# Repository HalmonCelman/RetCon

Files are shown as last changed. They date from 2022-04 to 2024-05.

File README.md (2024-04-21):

# RetCon

Mini Retro Console

Based on LLL language, works on FatFS.
Display: WG12864B1 V1.0-SFYLYHTC06
CPU: Atmega1284p

to run properly LLL( with FatFS ) you need to have at least 3K internal SRAM memory

## Dependencies
- avr-gcc
- avrdude
- cmake

## Build and Run

in program/
```
./configure.sh
./build.sh
./upload.sh
```

*if you are not using usbasp you should change upload.sh*

## Schematic

you can find schematic in `schematic_and_others/schematic` and modify it in KiCAD, or just look below:

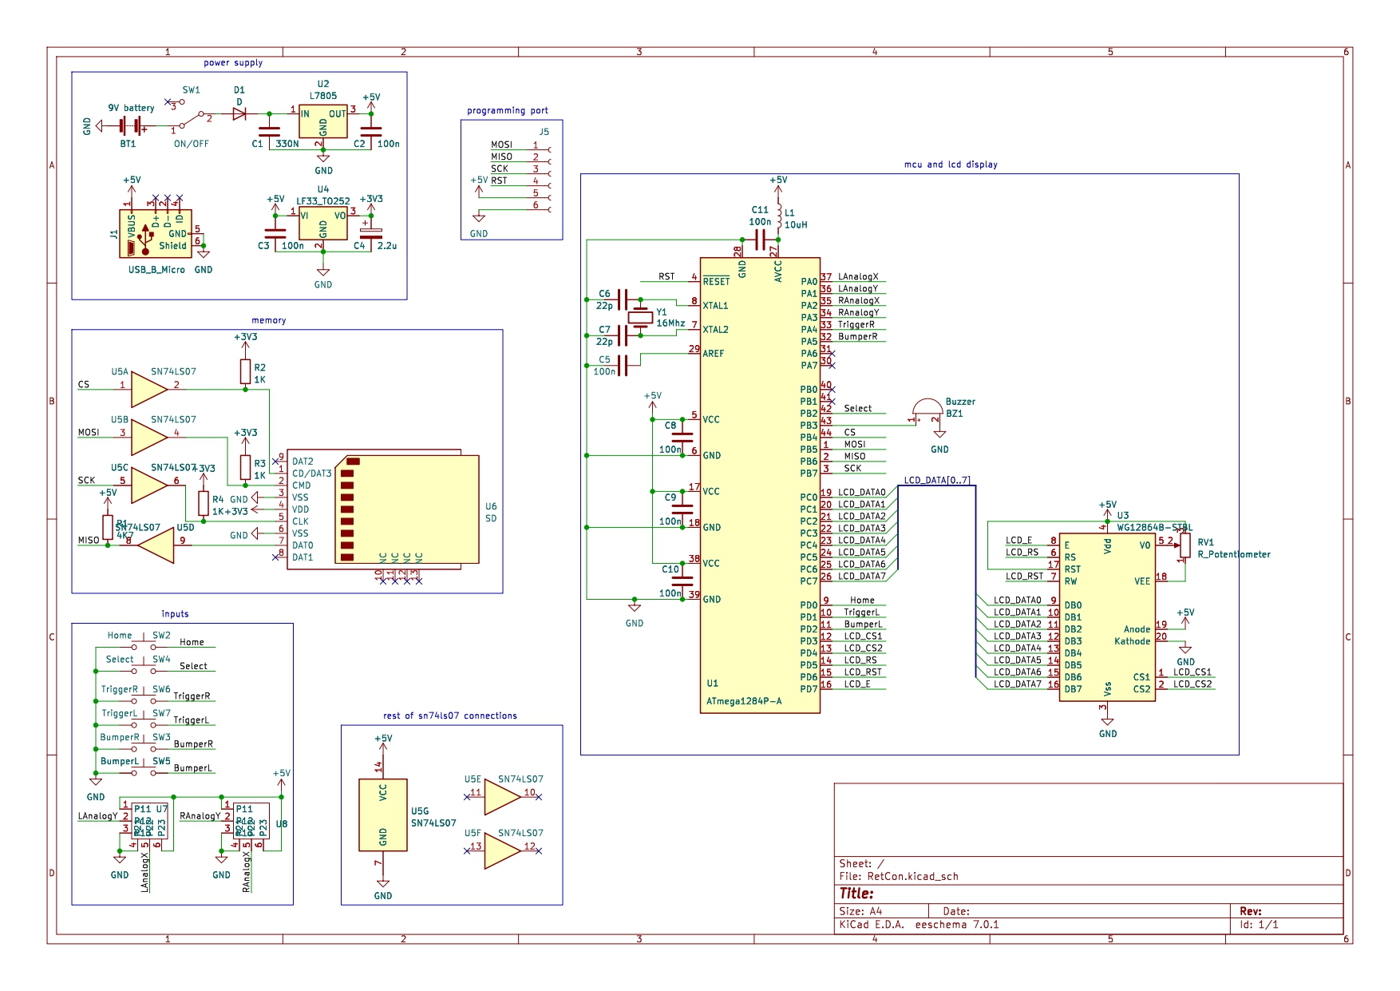
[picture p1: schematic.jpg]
Schematic schematic of RetCon


## Board and Reality

here are some pictures how the board has been designed and how it looks in reality

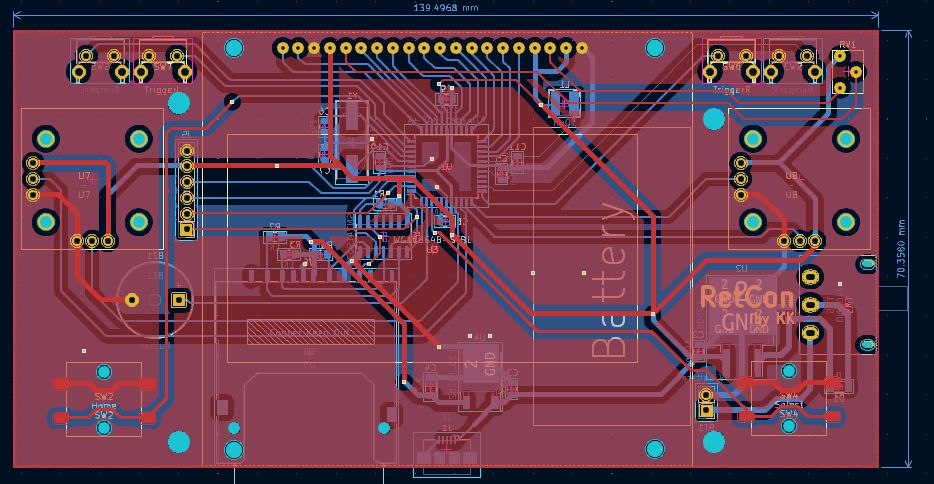
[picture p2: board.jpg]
Board board design


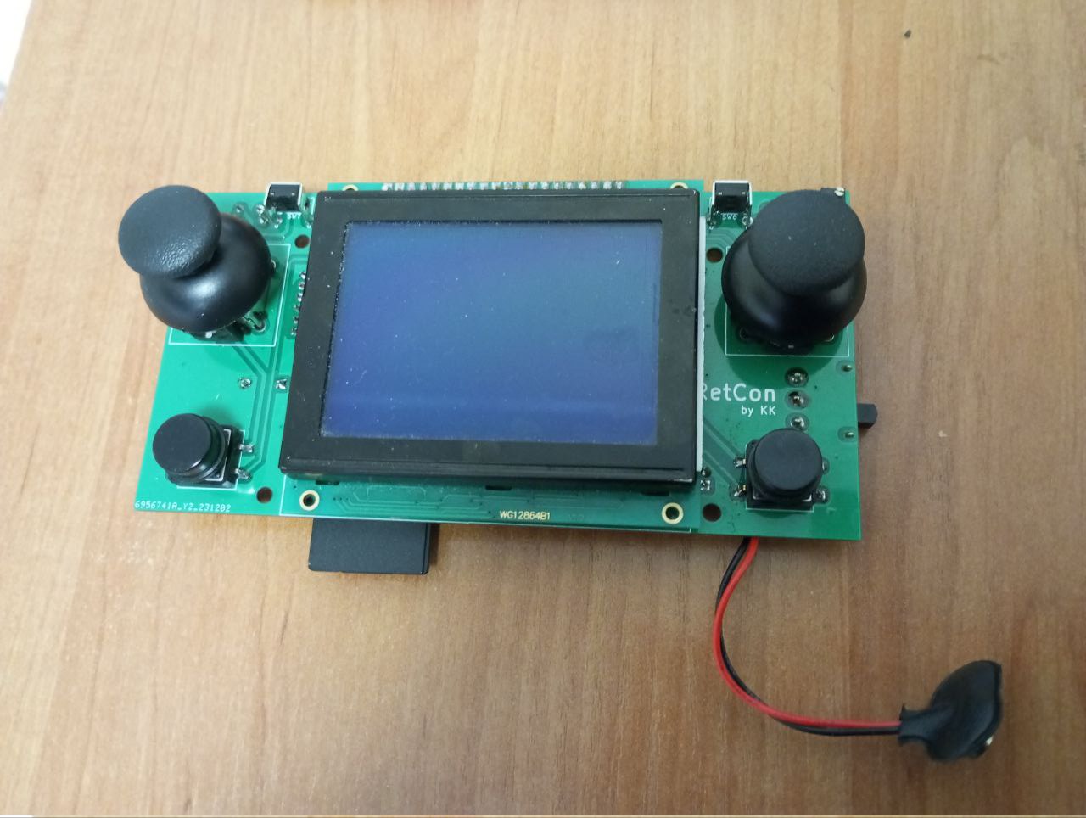
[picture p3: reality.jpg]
Reality reality


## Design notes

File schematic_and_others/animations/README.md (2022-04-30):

How to create animation for this system?

You have two options

A. to do automatically:

1. Create animation in gimp or another program.
2. Export to *gif
3. Convert to *.wbmp with https://convertio.co/pl/gif-wbmp/ or any similiar converter
4. Download zip
5. Unpack to animacje/frames/
6. run from terminal ./manima.sh
7. write how your gif was named ->f.e your gif - a.gif then you write a
8. copy prefix (if you have files in frame/a f.e. abc0.wbmp abc1.wbmp then you should copy abc) and paste it
9. give how you would name your animation
10. done! your animation is in folder exported/

OR

B. manually
1. Create animation in gimp or another program.
2. Export to *gif
3. Convert to *.wbmp with https://convertio.co/pl/gif-wbmp/ or any similiar converter
4. Download zip
5. Unpack to animacje/frames/
6. run from terminal ./rrator.sh
7. write how your gif was named ->f.e your gif - a.gif then you write a
8. copy prefix (if you have files in frame/a f.e. abc0.wbmp abc1.wbmp then you should copy abc) and paste it
9. give how you would name your animation
10. run ./condator.sh
11. write this same as in 7 point
12. write this same as in 9 point
13. run ./exportator.sh
14. write this same as in point 9 and 12
15. done! your animation is in folder exported/

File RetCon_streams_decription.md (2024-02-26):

# RetCon Streams Description

> This file decribes IN and OUT recieved from LLL, and it's functions

**! *0 values mean that parameter isn't processed but still 1 parameter is necessary in program, I recommend to write in his place @0* !**

**! *more than 1 value should be given by range, or by separating out command into multiple out commands with same stream* !**

## for OUT:
> ### 0. Error 
> 
> > Display error information
> > 
> > 1 value
> > - error number
>
> ### 1. Refreshes the screen
> 
> > 0 values
>
> ### 2. Clear screen buffer
> > Clears all the screen buffer
> > (if double buffering isn't used - clears screen)
> >
> > 0 values
> 
> ### 3. SetPixel
> > Sets pixel in screen buffer
> > 
> > 2 values
> > - X axis [0:127]
> > - Y axis [0:63]
>
> ### 4. ClearPixel
> > Clears pixel in screen buffer
> > 
> >  2 values
> > - X axis [0:127]
> > - Y axis [0:63]
>
> ### 5. WriteChar
> > Write Char on screen, x and y indicates position of top left pixel of letter, letters size are 5x7 
> > 
> >  3 values
> > - X axis [0:121]
> > - Y axis [0:63]
> > - char
> 
> ### 6. Stroke Rect
> > Draws a rectangle which isn't filled inside
> > 
> >  4 values
> >  - X start axis [0:127]
> >  - Y start axis [0:63]
> >  - X length
> >  - Y length
> 
> ### 7. Fill Rect
> > Draws a rectangle which is filled inside
> > 
> >  4 values
> >  - X start axis [0:127]
> >  - Y start axis [0:63]
> >  - X length
> >  - Y length
> 
> ### 8. Beep
> > Beep with buzzer for up to 255 ms (this don't stop program from execuitng)
> >
> > *believe me you don't want to turn this buzzer for longer time,
> >  but chill, in the RetCon v1.1 you should be able to play some music with it*
> >
> > 1 value
> > - time of beeping
> ### 9. Delay - in miliseconds
> > Stop executing anything for up to 65535 ms
> >
> > 2 values
> > - 16 bits value
> >
> ### 10. setTimer
> > sets timer which decerase every milisecond and stops at 0
> >
> >  2 values
> >  - 16 bits value

## for IN:

> ### 0. Error Stream
> > Check if any error exist, if yes get his number
> > 
> > 1 value
> > - error number
> >
> ### 1. get 1-0 buttons value
> > if button is pressed, at its position 1 is set, for positions see buttons.pdf
> >
> > 1 value
> > - bits for all buttons
> >
> ### 2. get analog 1 value
> > 
> > gets value from left analog
> > 
> > - 1 value
> >
> ### 3. get analog 2 value
> > 
> > gets value from right analog
> > 
> > - 1 value
>
> ### 10. getTimer
> > gets timer value
> >
> >  2 values
> >  - 16 bits value

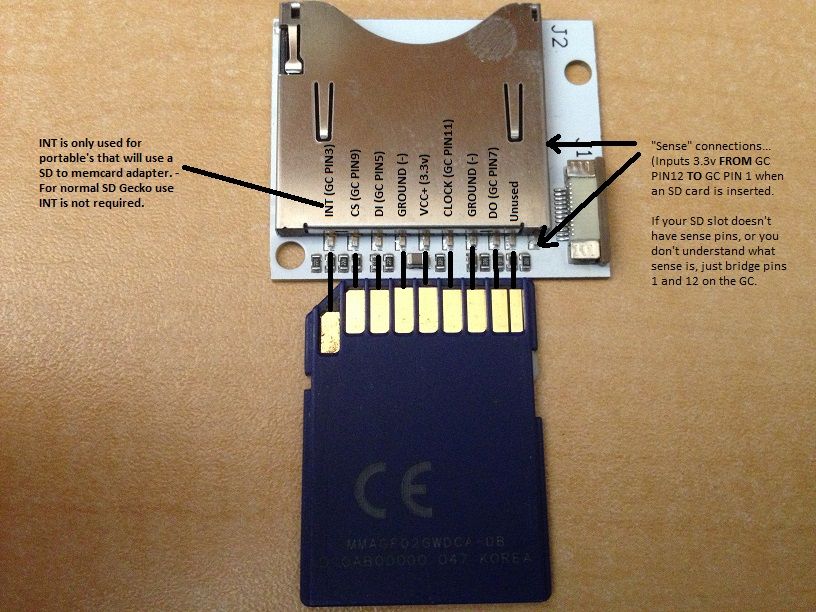
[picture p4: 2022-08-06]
schematic_and_others/documentations/SD_pinout.jpg

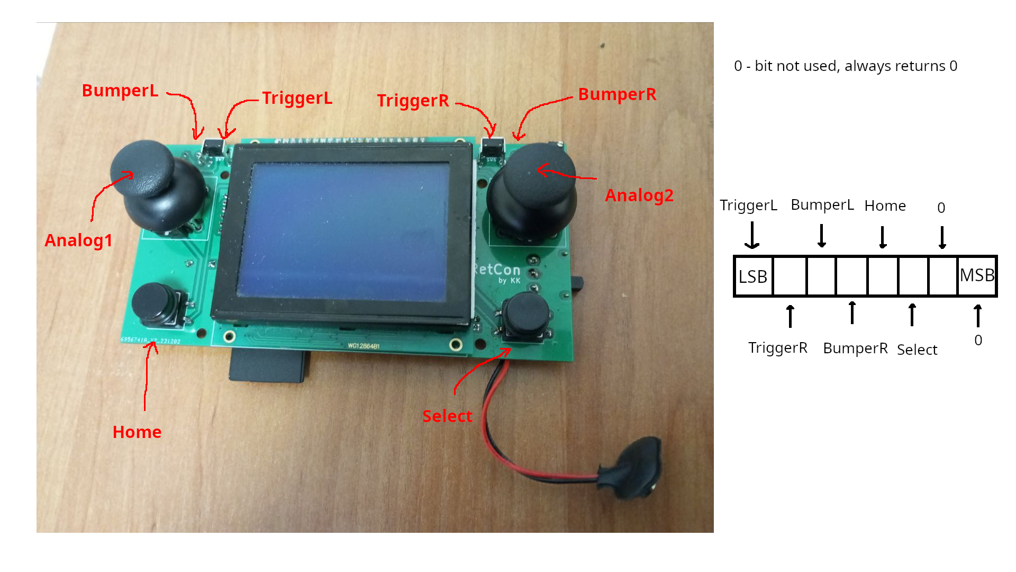
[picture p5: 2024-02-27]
buttons.png

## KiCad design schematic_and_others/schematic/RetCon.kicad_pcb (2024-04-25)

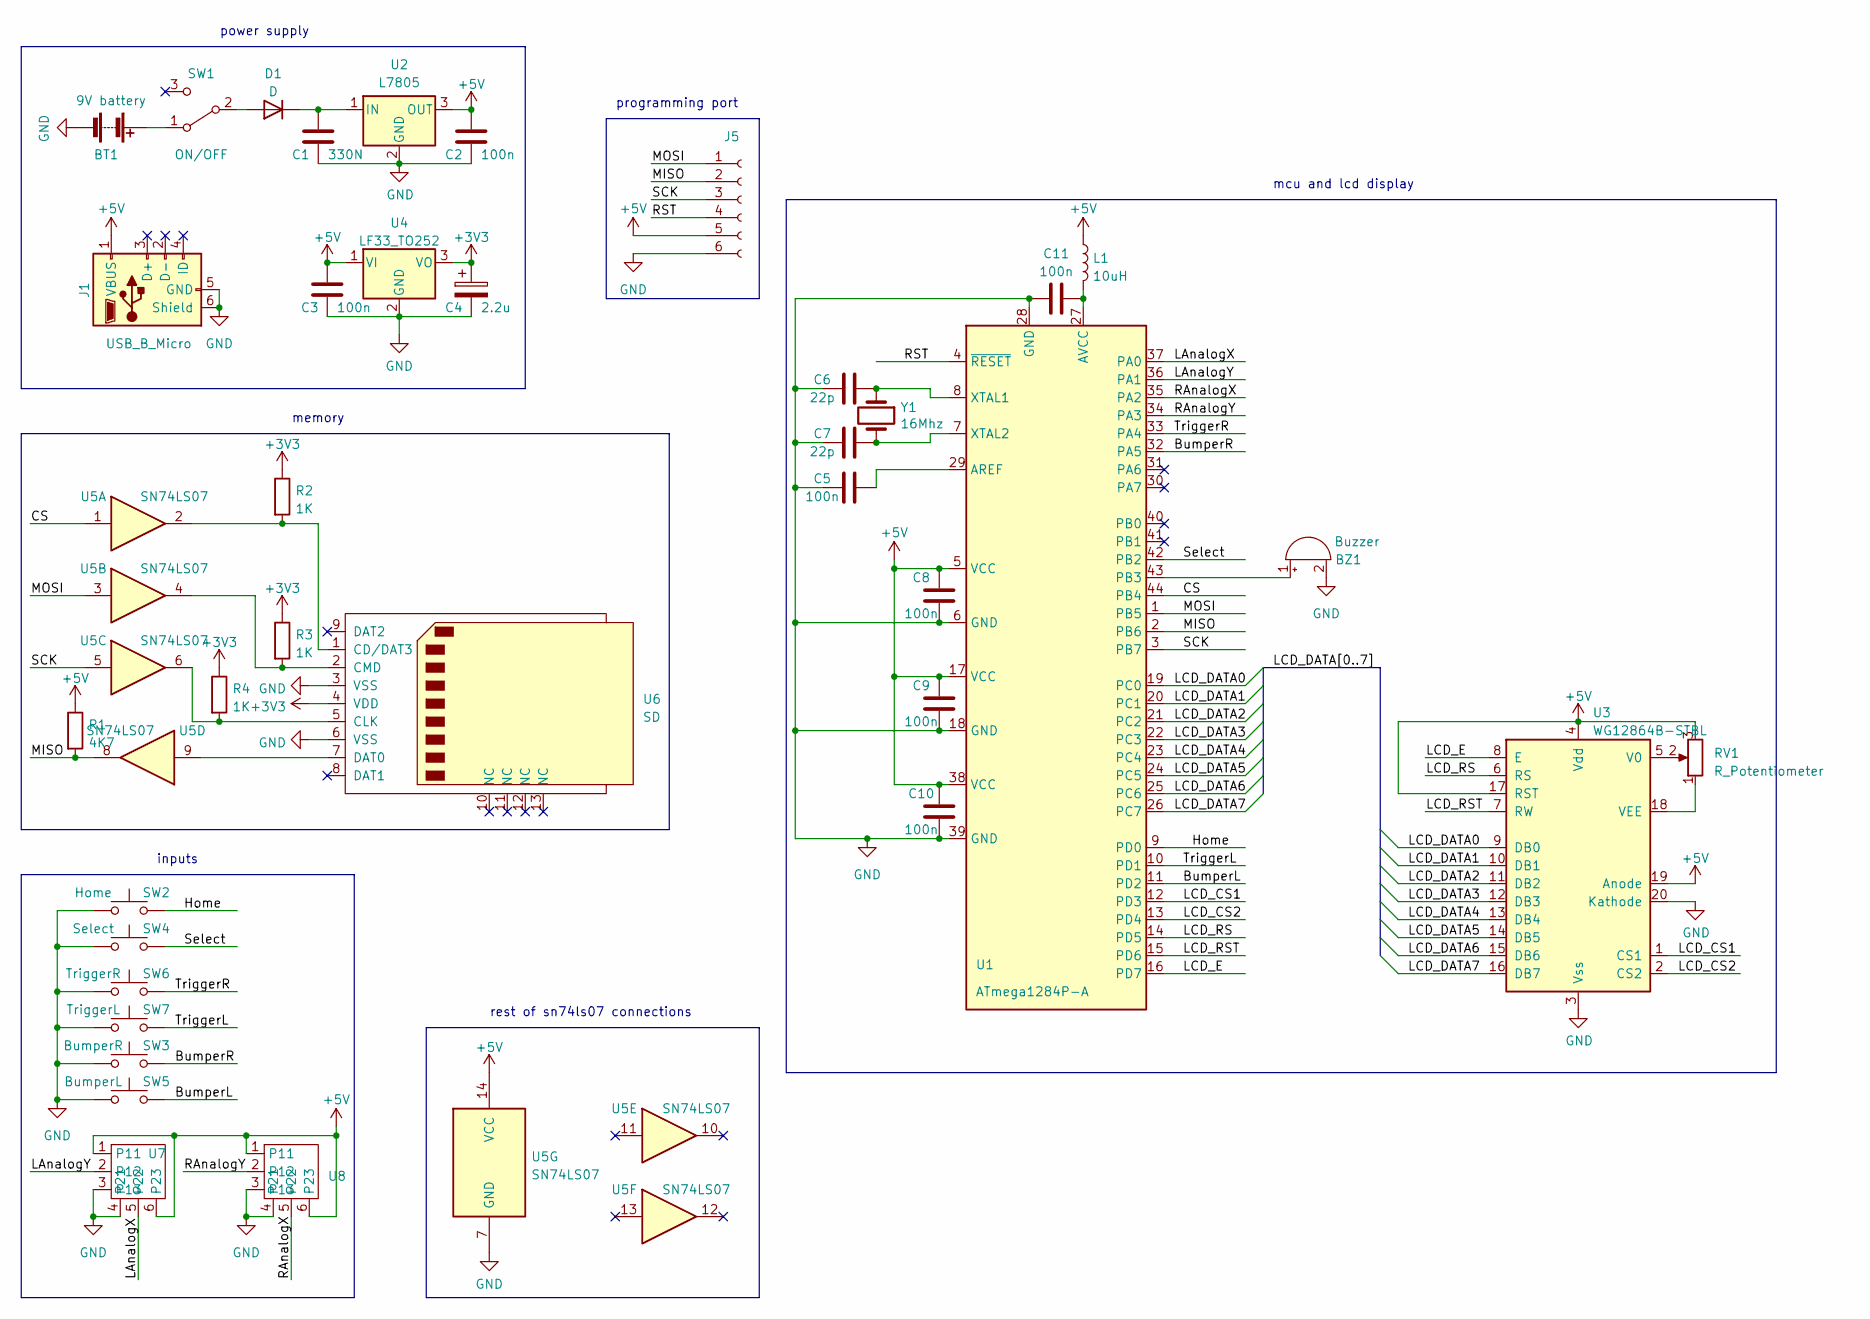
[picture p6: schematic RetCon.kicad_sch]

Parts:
BT1: 9V battery; PinSocket_1x02_P2.54mm_Vertical
BZ1: Buzzer; Buzzer_12x9.5RM7.6
C1: 330N; C_0805_2012Metric
C2, C3, C5, C8, C9, C10, C11: 100n; C_0805_2012Metric
C4: 2.2u; C_1206_3216Metric
C6, C7: 22p; C_0805_2012Metric
D1: D; C_1206_3216Metric
J1: USB_B_Micro; USBMicro-SMD
J5: PinSocket_1x06_P2.54mm_Vertical
L1: 10uH; L_Bourns-SRN4018
R1: 4K7; R_0805_2012Metric_Pad1.20x1.40mm_HandSolder
R2, R3, R4: 1K; R_0805_2012Metric_Pad1.20x1.40mm_HandSolder
RV1: R_Potentiometer; potentiometer10K
SW1: ON/OFF; Button_Switch
SW2: Home; buttonSMD_withHoles
SW3: BumperR; SW_Tactile_SPST_Angled_PTS645Vx31-2LFS
SW4: Select; buttonSMD_withHoles
SW5: BumperL; SW_Tactile_SPST_Angled_PTS645Vx31-2LFS
SW6: TriggerR; SW_Tactile_SPST_Angled_PTS645Vx31-2LFS
SW7: TriggerL; SW_Tactile_SPST_Angled_PTS645Vx31-2LFS
U1: ATmega1284P-A; TQFP-44_10x10mm_P0.8mm
U2: L7805; TO-263-2
U3: WG12864B-STBL; WG12864BL
U4: LF33_TO252; TO-252-2
U5: SN74LS07; SO-14_3.9x8.65mm_P1.27mm
U6: SD; SD_Kyocera_145638009511859+
U7, U8: joystickTHT
Y1: 16Mhz; Crystal_SMD_HC49-SD

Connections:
+3V3: C4.1, R2.1, R3.1, R4.1, U4.3 (VO), U6.4 (VDD)
+5V: C2.1, C3.1, C8.2, C9.2, C10.2, J1.1 (VBUS), J5.5, L1.1, R1.1, RV1.3, U1.5 (VCC), U1.17 (VCC), U1.38 (VCC), U2.3 (OUT), U3.4 (Vdd), U3.17 (RST), U3.19 (Anode), U4.1 (VI), U5.14 (VCC), U7.1 (P11), U7.6 (P23), U8.1 (P11), U8.6 (P23); also elsewhere on the board
/BumperL: SW5.2, U1.11 (PD2)
/BumperR: SW3.1, U1.32 (PA5)
/CS: U1.44 (PB4), U5.1
/Home: SW2.2, U1.9 (PD0)
/LAnalogX: U1.37 (PA0), U7.5 (P22)
/LAnalogY: U1.36 (PA1), U7.2 (P12)
/LCD_CS1: U1.12 (PD3), U3.1 (CS1)
/LCD_CS2: U1.13 (PD4), U3.2 (CS2)
/LCD_DATA0: U1.19 (PC0), U3.9 (DB0)
/LCD_DATA1: U1.20 (PC1), U3.10 (DB1)
/LCD_DATA2: U1.21 (PC2), U3.11 (DB2)
/LCD_DATA3: U1.22 (PC3), U3.12 (DB3)
/LCD_DATA4: U1.23 (PC4), U3.13 (DB4)
/LCD_DATA5: U1.24 (PC5), U3.14 (DB5)
/LCD_DATA6: U1.25 (PC6), U3.15 (DB6)
/LCD_DATA7: U1.26 (PC7), U3.16 (DB7)
/LCD_E: U1.16 (PD7), U3.8 (E)
/LCD_RS: U1.14 (PD5), U3.6 (RS)
/LCD_RST: U1.15 (PD6), U3.7 (RW)
/MISO: J5.2, R1.2, U1.2 (PB6), U5.8
/MOSI: J5.1, U1.1 (PB5), U5.3
/RAnalogX: U1.35 (PA2), U8.5 (P22)
/RAnalogY: U1.34 (PA3), U8.2 (P12)
/RST: J5.4, U1.4 (~RESET)
/SCK: J5.3, U1.3 (PB7), U5.5
/Select: SW4.2, U1.42 (PB2)
/TriggerL: SW7.2, U1.10 (PD1)
/TriggerR: SW6.1, U1.33 (PA4)
GND: BT1.2 (-), BZ1.2 (+), C1.2, C2.2, C3.2, C4.2, C5.1, C6.1, C7.1, C8.1, C9.1, C10.1, C11.1, J1.5 (GND), J1.6 (Shield), J5.6, SW2.1, SW3.2, SW4.1, SW5.1, SW6.2, SW7.1, U1.6 (GND), U1.18 (GND), U1.28 (GND), U1.39 (GND), U2.2 (GND), U3.3 (Vss), U3.20 (Kathode), U4.2 (GND), U5.7 (GND), U6.3 (VSS), U6.6 (VSS), U7.3 (P13), U7.4 (P21), U8.3 (P13), U8.4 (P21); also elsewhere on the board
unnamed: BT1.1 (+), SW1.1 (A)
unnamed: BZ1.1 (-), U1.43 (PB3)
unnamed: D1.2 (A), SW1.2 (B)
unnamed: C1.1, D1.1 (K), U2.1 (IN)
unnamed: C5.2, U1.29 (AREF)
unnamed: C11.2, L1.2, U1.27 (AVCC)
unnamed: C6.2, U1.8 (XTAL1), Y1.1
unnamed: C7.2, U1.7 (XTAL2), Y1.2
unnamed: RV1.2, U3.5 (V0)
unnamed: RV1.1, U3.18 (VEE)
unnamed: R2.2, U5.2, U6.1 (CD/DAT3)
unnamed: R4.2, U5.6, U6.5 (CLK)
unnamed: R3.2, U5.4, U6.2 (CMD)
unnamed: U5.9, U6.7 (DAT0)

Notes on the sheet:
mcu and lcd display
inputs
power supply
programming port
memory
rest of sn74ls07 connections

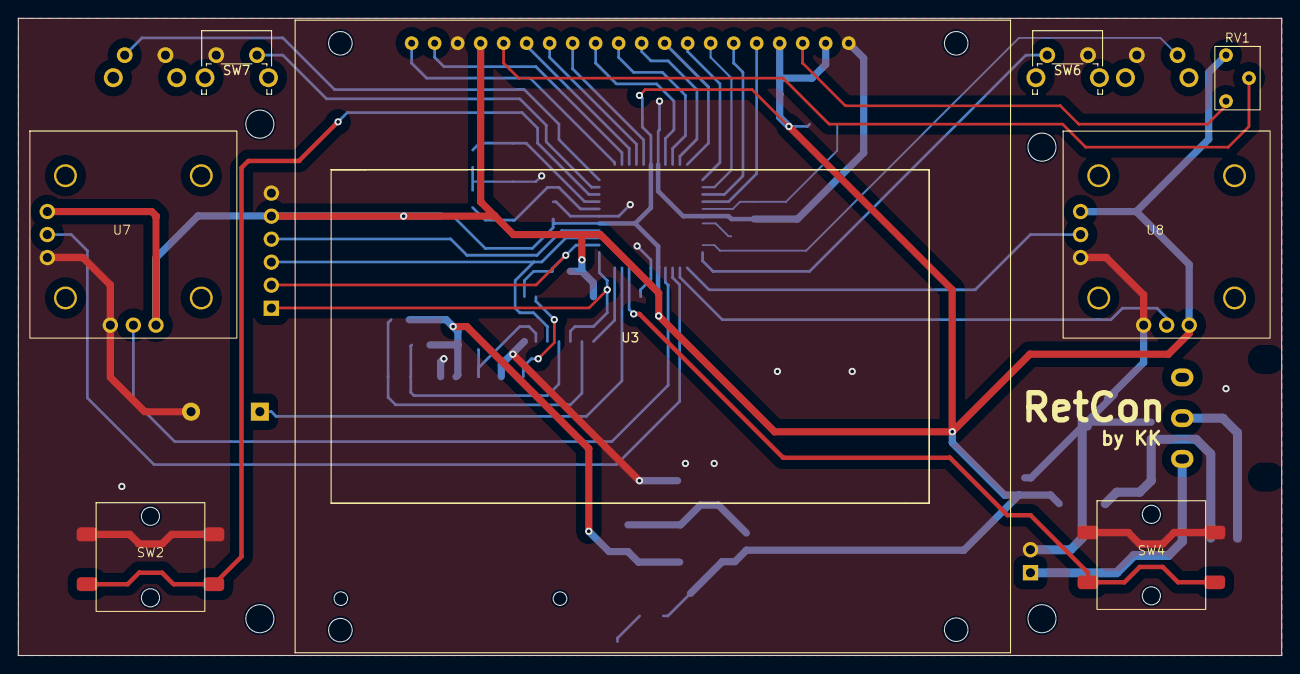
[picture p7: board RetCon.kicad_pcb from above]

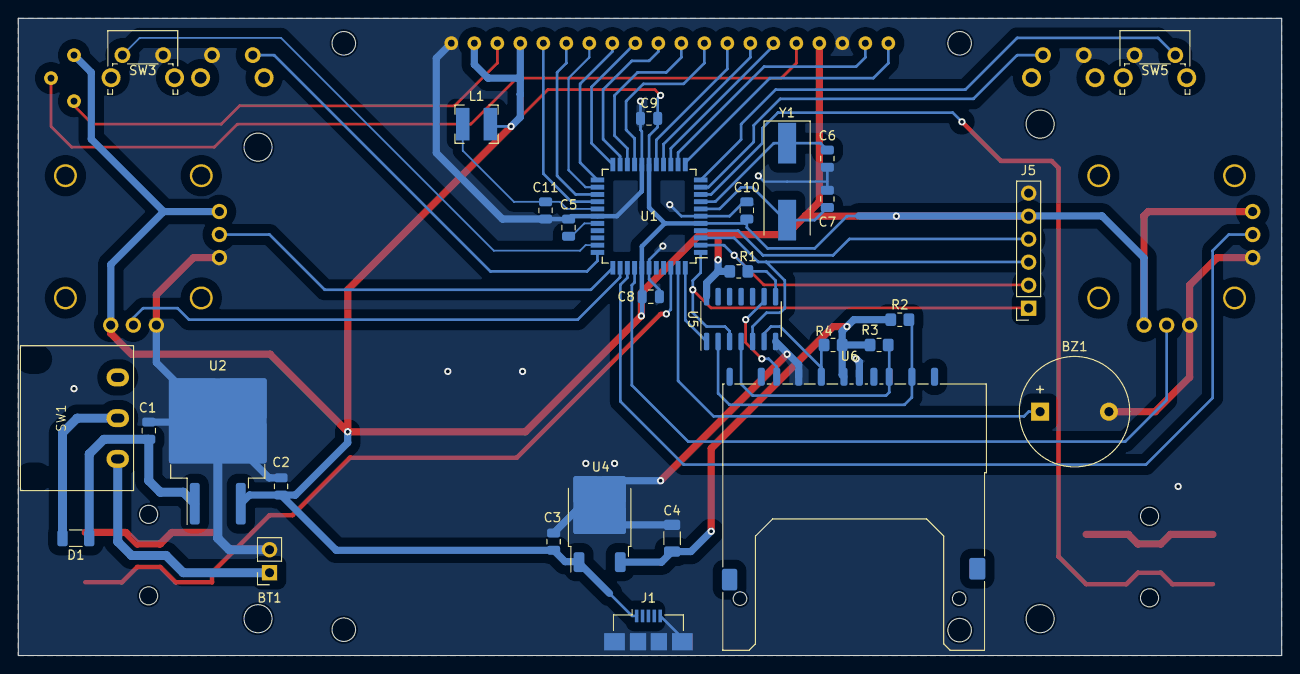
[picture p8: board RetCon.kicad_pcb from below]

Board: 2 copper layers, 139.5 x 70.4 mm, 42 parts (30 on the bottom side), 45 nets.

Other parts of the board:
J1#2: USB_B_Micro; USBMicro-SMD
J2: Hole2; One_hole
J3: Hole3; One_hole
J4: Hole4; One_hole

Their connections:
+5V: J1#2.1 (VBUS); also elsewhere on the board
GND: J1#2.5 (GND), J1#2.6 (Shield); also elsewhere on the board

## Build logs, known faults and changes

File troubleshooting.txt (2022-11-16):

trouble: rc=-1 connection failed

OK, so when microcontroller doesn't aswer try avrdude with -B300 flag ,
 it sets SCK to 2KHz so it can communicate even if microcontroller is going really slow
f.e. avrdude -c usbasp -p m1284p -B300

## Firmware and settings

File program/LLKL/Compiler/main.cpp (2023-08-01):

#include <iostream>
#include <fstream>

typedef enum{
    LLL_ADD = 0,
    LLL_ADDI,
    LLL_SUB,
    LLL_SUBI,
    LLL_MUL,
    LLL_MULI,
    LLL_DIV,
    LLL_DIVI,
    LLL_AND,
    LLL_ANDI,
    LLL_OR,
    LLL_ORI,
    LLL_NOT,
    LLL_INC,
    LLL_DEC,
    LLL_SER,
    LLL_SERI,
    LLL_LJMP,
    LLL_JMP,
    LLL_RET,
    LLL_CMP,
    LLL_CMPI,
    LLL_SEQ,
    LLL_DEQ,
    LLL_SLO,
    LLL_DLO,
    LLL_SGR,
    LLL_DGR,
    LLL_IN,
    LLL_OUT
} lll_command_list;




std::ofstream out_file;
std::ifstream in_file;
std::string line;

bool status=false;

void findAllAndChange(void);
lll_command_list compareCommands(void);
std::string getStringFromString(std::string,unsigned int);

int main(int args, char **argv){
    if(args < 3){
        std::cout<<"enter files to compile"<<std::endl;
    }else{
        
        out_file.open(argv[1],std::ios::out | std::ios::trunc);

        std::cout<<"loading files..."<<std::endl;
        for(int i=2;i<args;i++){
            std::cout<<"Compiling file: "<<argv[i]<<std::endl;
            in_file.open(argv[i],std::ios::in);
            while(std::getline(in_file,line)){
                findAllAndChange();
            }
        }
    }
    return 0;
}

void replace_spaces_by_nulls(std::string * line){
    for(int i=0;i<line->length();i++){
        if((*line)[i]==' '){
            (*line)[i]=(char)0;
        }
    }
}

std::string getStringFromString(std::string str1,unsigned int whichOne){
    std::string str2;
    for(int i=0;i<str1.length();i++){
        switch(str1[i]){
            case 0:
            case ' ':
            case '\n':
                if(status){
                    if(!whichOne){
                        return str2;
                    }else{
                        whichOne--;
                    }
                    status=false;
                }
            break;
            default:
                status=true;
                if(!whichOne){
                    str2.push_back(str1[i]);
                }
        };
    }

    if(!whichOne){
        return str2;
    }

    return " ";
}


lll_command_list compareCommands(std::string strcommand){
    if("add" == strcommand){ return LLL_ADD; }
    if("addi" == strcommand){ return LLL_ADDI; }
    if("sub" == strcommand){ return LLL_SUB; }
    if("subi" == strcommand){ return LLL_SUBI; }
    if("mul" == strcommand){ return LLL_MUL; }
    if("muli" == strcommand){ return LLL_MULI; }
    if("div" == strcommand){ return LLL_DIV; }
    if("divi" == strcommand){ return LLL_DIVI; }
    if("and" == strcommand){ return LLL_AND; }
    if("andi" == strcommand){ return LLL_ANDI; }
    if("or" == strcommand){ return LLL_OR; }
    if("ori" == strcommand){ return LLL_ORI; }
    if("not" == strcommand){ return LLL_NOT; }
    if("inc" == strcommand){ return LLL_INC; }
    if("dec" == strcommand){ return LLL_DEC; }
    if("ser" == strcommand){ return LLL_SER; }
    if("seri" == strcommand){ return LLL_SERI; }
    if("ljmp" == strcommand){ return LLL_LJMP; }
    if("jmp" == strcommand){ return LLL_JMP; }
    if("ret" == strcommand){ return LLL_RET; }
    if("cmp" == strcommand){ return LLL_CMP; }
    if("cmpi" == strcommand){ return LLL_CMPI; }
    if("seq" == strcommand){ return LLL_SEQ; }
    if("deq" == strcommand){ return LLL_DEQ; }
    if("slo" == strcommand){ return LLL_SLO; }
    if("dlo" == strcommand){ return LLL_DLO; }
    if("sgr" == strcommand){ return LLL_SGR; }
    if("dgr" == strcommand){ return LLL_DGR; }
    if("in" == strcommand){ return LLL_IN; }
    if("out" == strcommand){ return LLL_OUT; }

    std::cout<<"ERROR: wrong command: "<<strcommand<<std::endl;
    exit(0);
}

void findAllAndChange(void){
    std::string str;
    unsigned int i=0;
    do{
        str=getStringFromString(line,i);
        if(str != " "){
        if(str[0] == '&' || str[0] == '*' || str[0] == ':'){ //register or label
            out_file<<(char)str[0];
            out_file<<(char)std::stoi(&str[1]);
        }else if((str[0] >= '0') && (str[0] <= '9')) { //INT
            out_file<<(char)std::stoi(str);
        }else{ //command
            out_file<<(char)compareCommands(str);
        }
        i++;
        }
    }while(str!=" ");
}

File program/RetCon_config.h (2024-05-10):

#ifndef RETCON_CONFIG_H
#define RETCON_CONFIG_H

#define PREP_TRICK_DDR(x,y) x##y
#define DDR(x) PREP_TRICK_DDR(DDR,x)

#define PREP_TRICK_PORT(x,y) x##y
#define PORT(x) PREP_TRICK_PORT(PORT,x)

#define PREP_TRICK_PIN(x,y) x##y
#define PIN(x) PREP_TRICK_PIN(PIN,x)
///__bindings
// all triggers, bumpers and buttons active high
#define T_L_PIN 1  //trigger left
#define T_L_PORT D

#define T_R_PIN 4  //trigger right
#define T_R_PORT A

#define B_L_PIN 2  //bumper left
#define B_L_PORT D

#define B_R_PIN 5  //left
#define B_R_PORT A

#define HOME_PIN 0  //Home
#define HOME_PORT D

#define SELECT_PIN 2  //Select
#define SELECT_PORT B

#define BUZZ_PIN 3  //buzzer - active high
#define BUZZ_PORT B

// analog joysticks
#define ANALOG_PORT A

#define AN1_X_PIN 0
#define AN1_Y_PIN 1

#define AN2_X_PIN 2
#define AN2_Y_PIN 3

// not connected analog inputs, disabled to minimize power consumption
#define NC1 6
#define NC2 7

#endif

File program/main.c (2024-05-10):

/*
*************************************************
*         by KK        RetCon core              *
*************************************************
 */
#define F_CPU 16000000UL
#ifndef __AVR_ATmega1284P__
    #define __AVR_ATmega1284P__
#endif

/// __ekran WinCom WG12864D ze sterownikiem KS0108
#include <KS0108.h>
#include <multi_buff.h>
#include <additional_graphics.h>

/// LLL
#include <LLL.h>

//system
#include <base.h>
#include <input.h>
#include <config.h>


#include <avr/io.h>
int main(void)
{
    key_init();
    //***************
    ///->start ekranu
    GLCD_Initalize();
    GLCD_ClearScreen();
    GLCD_B_ClearScreen(); //clear buffer

    init_buffering();

    ///->main program
    GLCD_B_ClearScreen();
    GLCD_B_WriteString("starting KoKOS...",0,0);
    GLCD_r;

    init_fs();

    LLL_init();

    //LLL_run("program.l");
    while(1){
        //lll_send_info("joystick1 x",joysticks[0]);
        delay(200);
        //lll_send_info("joystick1 y",joysticks[1]);
        // delay(1000);
        // lll_send_info("joystick2 x",joysticks[2]);
        // delay(1000);
        lll_send_info("joystick2 y",joysticks[3]);
        // delay(1000);
    }
    LLL_end();

    close_fs();

    while(1){

    }
    return 0;
}

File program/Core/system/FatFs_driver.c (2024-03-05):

#include <stdint.h>
#include <avr/io.h>

#define SCK 7
#define MISO 6
#define MOSI 5
#define CS 0 //PORTA

/*
 set CS pin to HIGH state - 3,3V 
*/
void FatFs_CS_HIGH(void){
    PORTA|=(1<<CS);
}

/*
 set CS pin to LOW state - 3,3V 
*/
void FatFs_CS_LOW(void){
    PORTA &=~ (1<<CS);
}

/*
Initialize all pins and SPI here
*/
void FatFs_power_on(void)
{
    DDRB |= (1<<MOSI)|(1<<SCK)|(1<<PB4); //SS output to working SPI
    DDRA |= (1<<CS);
	DDRB &=~ (1<<MISO);
    PORTB |= (1<<MOSI);
    PORTA &=~ (1<<CS);
	/* Enable SPI module with SPI2X */
    SPCR |= (1<<SPE)|(1<<MSTR)|(1<<SPI2X);
}

/*
Turn off spi and pins here
*/
void FatFs_power_off(void)
{
	/* Disable SPI function */
	SPCR &=~ (1<<SPE) | (1<<MSTR)|(1<<SPI2X);

	PORTA|=(1<<CS);
}

uint8_t FatFs_SPI_SendRcv(uint8_t data){
    SPDR = data;
    while(!(SPSR & (1<<7)));
    return SPDR;
}

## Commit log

2022-04-18 Pierwszy commit
    Kod z innego projektu( KoKOS mini games )
    [schemat_dip40.kicad_pcb, schemat_dip40.sch]
2022-04-21 Spaghetti dodane
    Dodano przyciski do spaghetti układu
    [schemat_dip40.sch]
2022-04-25 Kupa roboty
    Wstepna plytka PCB zaprojektowana dla niebieskiego ekranu, 1 opornik 0R THT
    [schemat_dip40.kicad_pcb, schemat_dip40.sch]
2022-04-30 Schemat, scalenie i porzadki
    ->Zaktualizowano schemat
    ->Dodano skrypt manima.sh scalajacy poprzednie
    ->Dodano instrukcje tworzenia animacji
    [schemat_dip40.kicad_pcb, schemat_dip40.sch]
2022-05-09 Zmieniono uklad symboli na plytce
    [schemat_dip40.kicad_pcb, schemat_dip40.sch]
2022-05-09 Dodane polaczenia
    Dodano wszystkie polaczenia
    [schemat_dip40.kicad_pcb, schemat_dip40.sch]
2022-05-09 Lepsze sciezki, wypelnione GND
    [schemat_dip40.kicad_pcb]
2022-05-09 Buzzer
    Dodano buzzer
    [schemat_dip40.kicad_pcb, schemat_dip40.sch]
2022-05-12 Kolejne zmiany w szchemacie i plytce
    ->Dodano gniazdo ethernetowe i adapter zamiast zlacza 6pin
    aby byla mozliwa komunikacja miedzy konsolami
    ->zmieniono rozmieszczenie przyciskow
    ->drobne poprawki sciezek
    [adapter.kicad_pcb, adapter.sch, schemat_dip40.kicad_pcb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]
2022-05-21 Upraszczanie polaczen i poprawianie plytki
    Gotowe polaczenia do ekranu
    [adapter.kicad_pcb, adapter.sch, schemat_dip40.kicad_pcb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]
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2022-05-27 Wszystkie polaczenia
    Zrealizowano wszystkie polaczenia, wygaldaja okropnie ale sa XD
    [schemat_dip40.kicad_pcb, schemat_dip40.sch]
2022-05-27 Awful, but should work XD
    Strasznie brzydko, wszystkie sciezki do poprawy graficznej.
    Zamieniono przyciski tak aby były w dobrych miejscach
    [schemat_dip40.kicad_pcb, schemat_dip40.sch]
2022-05-28 Strefy i poprawki
    Dodano strefe GND i poprawiono juz czesc sciezek
    [schemat_dip40.kicad_pcb]
2022-05-29 Koncowe sciezki i adapter
    Ukonczono poprawianie sciezek i poprawnie zrobiono adapter
    [adapter.kicad_pcb, adapter.sch, schemat.kicad_pcb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]
2022-05-30 Logo i wymiary
    Dodano "by KK" i wymiary plyty glownej
    [adapter.kicad_pcb, schemat.kicad_pcb]
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2022-06-02 New branch konwerter started
    [konwerter.kicad_pcb, konwerter.sch, schemat.sch]
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2022-06-09 Gotowa plytka karty z konwerterem
    [konwerter.kicad_pcb, konwerter.sch]
2022-08-06 Konwerter update
    -> Poprawiony schemat konwertera
    -> Samodzielna płytka z konwerterem
    -> poprawiony symbol karty aby pasował do footprintu
    [konwerter.kicad_pcb, konwerter.sch]
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2022-08-11 Dodano schemat do adaptera karty
    -> wyprowadzenie waznych pinow karty jako 6 pinowe zlacze
    [karta.kicad_pcb, karta.sch, konwerter.kicad_pcb]
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2022-08-13 Dodano by KK i przygotowano do produkcji
    [karta.kicad_pcb]
2022-09-11 New version of KiCAD
    [konwerter.kicad_pcb]
2022-09-14 Kolejna zmiana konwertera
    -> poprzedni konwerter dzialal, ale nie wzialem
    pod uwage droputu na MOSFETach, wiec poziomy logiczne i tak
    sie nie zgadzaly
    -> zmieniony konwerter z gotowa plytka, dzialajacy juz na
    normalnych zasadach
    [karta.kicad_pcb, konwerter.kicad_pcb, konwerter.kicad_sch]
2022-09-21 Uzupelniony schemat niebieskiego
    -> dodano bufor i zastosowano konwersje napiec
    -> poprawiono symbol karty SD
    -> zapisano w formacie KiCAD 6.0
    [karta.kicad_sch, schemat.kicad_sch]
2022-09-21 Good footprints, before changes on PCB
    [schemat.kicad_pcb, schemat.kicad_sch, schemat.sch]
2022-09-21 Wstepne sciezki z buforem
    -> Dodano wstepne sciezki razem z buforem
    -> Tam gdzie bylo to wymagane zmieniono warstwe
    -> Dodano oporniki 0R we wlasciwych miejscach
    [schemat.kicad_pcb, schemat.kicad_sch]
2022-09-22 Awful but should work v2
    -> Wszystko zostalo prowizorycznie podlaczone
    -> uzyto 3 opornikow 0R
    [schemat.kicad_pcb, schemat.kicad_sch]
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2022-09-29 Ukonczone polaczenia
    -> skonczone polaczenia poprawionego schematu
    po przeniesieniu karty
    [schemat.kicad_pcb, schemat.kicad_sch]
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2022-10-06 Bardzo drobna zmiana plytki
    -> Wyrownano dw gorne skrajne otwory
    [schemat.kicad_pcb]
2022-11-04 Working board -> Atmega 1284p -> PetitFS -> SPI2X enabled -> !WARNING! key connected to PB4 resets MSTR bit in SPI configuration, in future should be moved to another pin
    [main.c]
2022-11-15 Working f_write() and FatFS
    -> corrected bug: disk_timerproc() has been working 25x too fast
    and that was cause of f_write 1 error
    -> delay timing corrected( delay has been working 2,5x too fast )
    [main.c]
2022-11-16 Exportator restored, and scripts to make animation corrected -> some changes also in rrator: prename instead of rename due to system change
    [main.cpp]
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2023-05-24 Better schema
    -> prevented reversed voltage
    -> added switch to select voltage source (external/internal)
    -> looks very unclear, needs correct
    [schemat.kicad_pcb, schemat.kicad_sch]
2023-07-20 Working CMake build and upload
    use following comands
    ./configure.sh
    ./build.sh
    ./upload.sh
    [adapter.kicad_pcb, adapter.kicad_sch, schemat.kicad_sch]
2023-07-25 External memory and LFN
    - external memory functions added and updated
    - LFN tried to add but linker error occured
    [main.c]
2023-08-02 LLKL name changed to LLL
    - also corrected add and addi
    [main.c, main.cpp]
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2023-08-09 Streams corrected, writing on screen
    - now you can have normal log file without drawing on screen
    [main.c]
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2023-11-07 Footprint for joysticks corrected
    [adapter.kicad_pcb, adapter.kicad_sch, adapter.sch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]
2023-11-08 More footprints updated - buttons - USB micro - coil
    [schemat.kicad_pcb, schemat.kicad_sch]
2023-11-23 Fully updated PCB of RetCon
    - It is in schemat/Niebieski folder
    - First checkout of parts has been done
    [schemat.kicad_pcb, schemat.kicad_sch]
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2023-12-30 Working lll on RetCon
    - still some errors during conversion in lll_send_info
    - external memory still isn't implemented
    [main.c]
2024-02-15 Streams update
    - some streams added
    - working "running square"
    [RetCon.kicad_sch]
2024-02-26 RetCon config file and small updates
    - names of triggers and bumpers updated
    - schematic, board updated
    - added picture how RetCon looks in reality
    [RetCon.kicad_pcb, RetCon.kicad_sch]
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2024-02-28 Buttons stream
    - board to fix: shortcuts between pins
    [RetCon_config.h, input.c, main.c]
2024-04-20 Better schematic
    - fixed mistake of connecting buttons to +5V
    - clearer schematic
    - PCB to update
    [RetCon.kicad_pcb, RetCon.kicad_sch]
2024-04-21 Board update
    - capacitors placed and connected
    - buttons connected to ground
    - need to update buttons and display footprints
    [RetCon.kicad_pcb, RetCon.kicad_sch]
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2024-05-10 ADC working
    - joysticks still seems to have issues in X axis
    [RetCon_config.h, input.c, main.c]
